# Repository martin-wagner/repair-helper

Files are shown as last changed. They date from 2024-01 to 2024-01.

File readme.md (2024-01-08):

# Reparaturhelfer

Platine mit Helferlein zur Reparatur von Röhrenradios
- Adapter für div. THT Kondensatoren auf Freiverdrahtung
- Adapter für Ladekondensator 50+50µF auf PCB mit Befestigungslöchern
- Platine "Selengleichrichter" (Bohrungen für 20mm, 27mm, 38mm und 80mm Gleichrichter, Ladekondensatoren)
- Platine "Bluetooth" (Spannungsversorgung Bluetoothmodul, Vorverstärker, Massetrennung)
- Platine "Entstörung" (Sicherheitskondensatoren, Anschluss an Chassis)

Die Platine ist < 100x100m². Somit kann diese bei den Standard Platinenherstellern bezogen werden. Der Nutzen ist im Bestückungsdruck markiert und kann leicht ausgesägt werden.

## Gleichrichter, Ladekondensatoren

Diese Platine dient als Ersatz für Selengleichrichter

- Bohrlöcher nach Standardmaßen gebräuchlicher Flachgleichrichter zur Befestigung an den vorhandenen Löchern.
- Platzierung von Entstörkondensatoren am Gleichrichter.
- Montage von verschiedneen Dropperwiderständen möglich.
- Montage der Filterkondensatoren möglich. Falls nicht benötigt kann die Platine entsprechend gekürzt werden.

## Bluetooth

Diese Platine erleichtert den Einbau eines Bluetooth Moduls ins Radio.

- Spannungsversorgung
- Vorverstärker um Ausganspegel des Bluetoothmoduls an den Line Input des Radios anzupassen
- Aufbau als Mono- oder Stereo Variante möglich
- Aufbau mit SO8 Standard OP Footprint. Möglich sind z.B. TL072 (billig) oder AD8656 (Rauscharm)
- Anschluss per Lötösen oder 3,5mm Klinke
- Montage des Bluetoothmoduls per 1mm, 1,27mm oder 2,54mm Lötleiste
- Footprint für zwei Taster, falls diese vom Bluetoothmodul benötigt werden

## Netzfilter

Diese Platine ermöglicht den Einbau eines Netzfilters mit zeitgemäßen Kondensatoren ins Gerät. Der vorgeschlagene Kondensator MUR DE1E3KX222MN ist vom Typ X1 / Y1, kann somit direkt am Netzanschluss und zwischen Netz und Chassis verwendet werden.

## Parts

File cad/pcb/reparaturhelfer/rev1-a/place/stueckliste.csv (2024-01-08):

Source: | /home/martin/elektronik/radios/reparaturhelfer/cad/pcb/reparaturhelfer/rev1-a/reparaturhelfer.kicad_sch
Date: | Mon 08 Jan 2024 13:20:33 CET
Tool: | Eeschema 7.0.10-7.0.10~ubuntu22.04.1
Generator: | /usr/share/kicad/plugins/bom_csv_grouped_by_value.py
Component Count: | 167
Collated Components:
Item | Qty | Reference(s) | Value | LibPart | Footprint | Datasheet | DNP | Bauteil | Placement | Voltage
1 | 7 | C201, C203, C207, C208, C213, C215, C216 | 100n | Device:C | Capacitor_SMD:C_0603_1608Metric | ~ |  | WE 885382206004
2 | 4 | C202, C209, C212, C214 | 1u | Device:C | Capacitor_SMD:C_0805_2012Metric | ~ |  | WE 885012207078
3 | 1 | C204 | 470u | saba-fernbedienung-rescue:CP-Device | Capacitor_THT:CP_Radial_D8.0mm_P5.00mm |  |  |  |  | 16V
4 | 3 | C205, C206, C210 | 10u | Device:C | Capacitor_SMD:C_1206_3216Metric | ~ |  | WE 885012208069
5 | 1 | C211 | ~ | saba-fernbedienung-rescue:CP-Device | Capacitor_THT:CP_Radial_D5.0mm_P2.50mm
6 | 2 | C301, C302 | 4n7 | Device:C | Capacitor_THT:C_Rect_L13.0mm_W3.0mm_P10.00mm_FKS3_FKP3_MKS4 | ~ |  | MKS4 4700/1000
7 | 4 | C303, C304, C305, C306 | 47u | saba-fernbedienung-rescue:CP-Device | Capacitor_THT:CP_Radial_D16.0mm_P7.50mm |  |  |  |  | 400V
8 | 2 | C401, C403 | C | Device:C | Capacitor_SMD:C_0805_2012Metric_Pad1.18x1.45mm_HandSolder | ~
9 | 3 | C402, C404, C406 | C | Device:C | Capacitor_THT:C_Rect_L13.0mm_W6.5mm_P7.50mm_P10.00mm | ~
10 | 1 | C405 | C | Device:C | Capacitor_SMD:C_1210_3225Metric_Pad1.33x2.70mm_HandSolder | ~
11 | 5 | C407, C409, C411, C412, C413 | C | Device:C | Capacitor_THT:C_Rect_L7.0mm_W3.5mm_P2.50mm_P5.00mm | ~
12 | 3 | C408, C410, C414 | C | Device:C | Capacitor_THT:C_Rect_L16.5mm_W7.0mm_P15.00mm_MKT | ~
13 | 3 | C415, C417, C419 | C | Device:C | Capacitor_THT:C_Rect_L10.0mm_W5.0mm_P5.00mm_P7.50mm | ~
14 | 2 | C416, C418 | C | Device:C | Capacitor_THT:C_Rect_L24.0mm_W10.1mm_P22.50mm_MKT | ~
15 | 1 | C420 | C | Device:C | Capacitor_THT:C_Rect_L29.0mm_W11.0mm_P27.50mm_MKT | ~
16 | 3 | C501, C502, C503 | 2n2 | Device:C | Capacitor_THT:C_Disc_D11.0mm_W5.0mm_P10.00mm | ~ |  | MUR DE1E3KX222MN
17 | 4 | D201, D202, D203, D204 | B140-E3 | Diode:B140-E3 | Diode_SMD:D_SMA | http://www.vishay.com/docs/88946/b120.pdf |  | Vishay B140-E3/61T
18 | 4 | D301, D302, D303, D304 | 1N4007 | Device:D | Diode_THT:D_A-405_P10.16mm_Horizontal | ~
19 | 3 | FID201, FID202, FID203 | Fiducial | Mechanical:Fiducial | Fiducial:Fiducial_1mm_Mask2mm | ~
20 | 5 | H201, H202, H203, H204, H502 | MountingHole | Mechanical:MountingHole | MountingHole:MountingHole_3.2mm_M3 | ~
21 | 8 | H301, H302, H303, H304, H305, H306, H307, H501 | MountingHole_Pad | Mechanical:MountingHole_Pad | MountingHole:MountingHole_3.2mm_M3_Pad | ~
22 | 1 | J201 | Conn_01x02 | Connector_Generic:Conn_01x02 | Connector_PinHeader_2.54mm:PinHeader_1x02_P2.54mm_Vertical | ~
23 | 1 | J202 | Conn_01x12 | Connector_Generic:Conn_01x12 | Connector_PinHeader_1.27mm:PinHeader_1x12_P1.27mm_Vertical | ~
24 | 1 | J203 | Conn_01x15 | Connector_Generic:Conn_01x15 | Connector_PinHeader_1.00mm:PinHeader_1x15_P1.00mm_Vertical | ~
25 | 1 | J204 | Conn_01x07 | Connector_Generic:Conn_01x07 | Connector_PinHeader_2.54mm:PinHeader_1x07_P2.54mm_Vertical | ~
26 | 1 | J205 | Conn_01x05 | Connector_Generic:Conn_01x05 | Connector_PinHeader_2.54mm:PinHeader_1x05_P2.54mm_Vertical | ~
27 | 1 | J206 | AudioJack3 | Connector:AudioJack3 | Connector_Audio:Jack_3.5mm_CUI_SJ1-3523N_Horizontal | https://www.farnell.com/datasheets/2028381.pdf |  | CLIFF FC68131
28 | 65 | J207, J208, J209, J301, J302, J303, J304, J305, J306, J307, J308, J309, J310, J311, J312, J313, J314, J315, J316, J317, J318, J319, J320, J321, J322, J323, J324, J325, J326, J401, J402, J403, J404, J405, J406, J407, J408, J409, J410, J411, J412, J413, J414, J415, J416, J417, J418, J419, J420, J421, J422, J423, J424, J425, J426, J427, J428, J429, J430, J431, J432, J433, J434, J435, J436 | Conn_01x01 | Connector_Generic:Conn_01x01 | Connector_PinHeader_2.54mm:PinHeader_1x01_P2.54mm_Vertical | ~
29 | 1 | J501 | Conn_01x03 | Connector_Generic:Conn_01x03 | Connector_PinHeader_2.54mm:PinHeader_1x03_P2.54mm_Vertical | ~
30 | 2 | R201, R211 | 1k | Device:R | Resistor_SMD:R_0603_1608Metric | ~
31 | 6 | R202, R205, R206, R212, R213, R214 | 100k | Device:R | Resistor_SMD:R_0603_1608Metric | ~
32 | 2 | R203, R204 | 0 | Device:R | Resistor_SMD:R_0603_1608Metric | ~ |  |  | NP
33 | 2 | R207, R215 | 10k | Device:R | Resistor_SMD:R_0603_1608Metric | ~
34 | 4 | R208, R216, R217, R218 | 1M | Device:R | Resistor_SMD:R_0603_1608Metric | ~ |  |  | NP
35 | 2 | R209, R210 | 220 | Device:R | Resistor_SMD:R_0603_1608Metric | ~
36 | 2 | RV201, RV202 | 20k lin | saba-fernbedienung-rescue:R_POT-Device | Potentiometer_SMD:Potentiometer_Vishay_TS53YJ_Vertical |  |  | 23A-20K
37 | 2 | SW201, SW202 | SW_Push | Switch:SW_Push | Button_Switch_THT:SW_PUSH_6mm | ~
38 | 2 | T201, T202 | 1:1 | Device:Transformer_1P_1S | local:Transformer_NF_EI14 | ~ |  |  | NP
39 | 1 | U201 | 1117 5.0V | Regulator_Linear:AP1117-50 | Package_TO_SOT_SMD:TO-252-3_TabPin2 | http://www.diodes.com/datasheets/AP1117.pdf |  | LD1117DT50CTR
40 | 1 | U202 | AD8656 | saba-fernbedienung-rescue:Opamp_Dual_Generic-Device | Package_SO:SOIC-8_3.9x4.9mm_P1.27mm | https://www.analog.com/media/en/technical-documentation/data-sheets/AD8655_8656.pdf |  | AD8656ARZ

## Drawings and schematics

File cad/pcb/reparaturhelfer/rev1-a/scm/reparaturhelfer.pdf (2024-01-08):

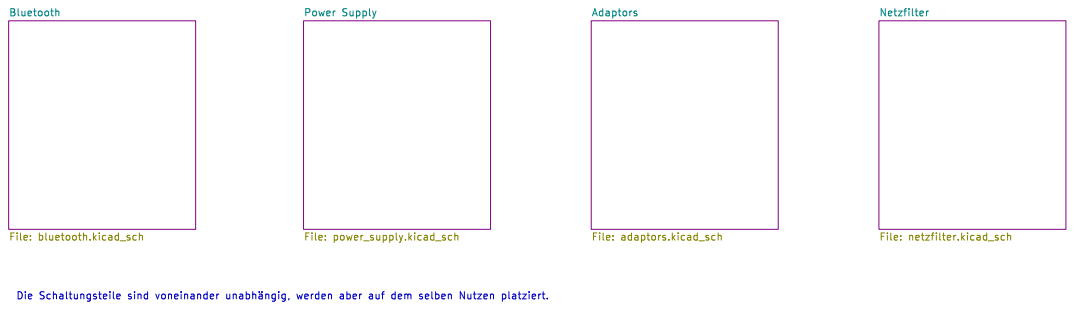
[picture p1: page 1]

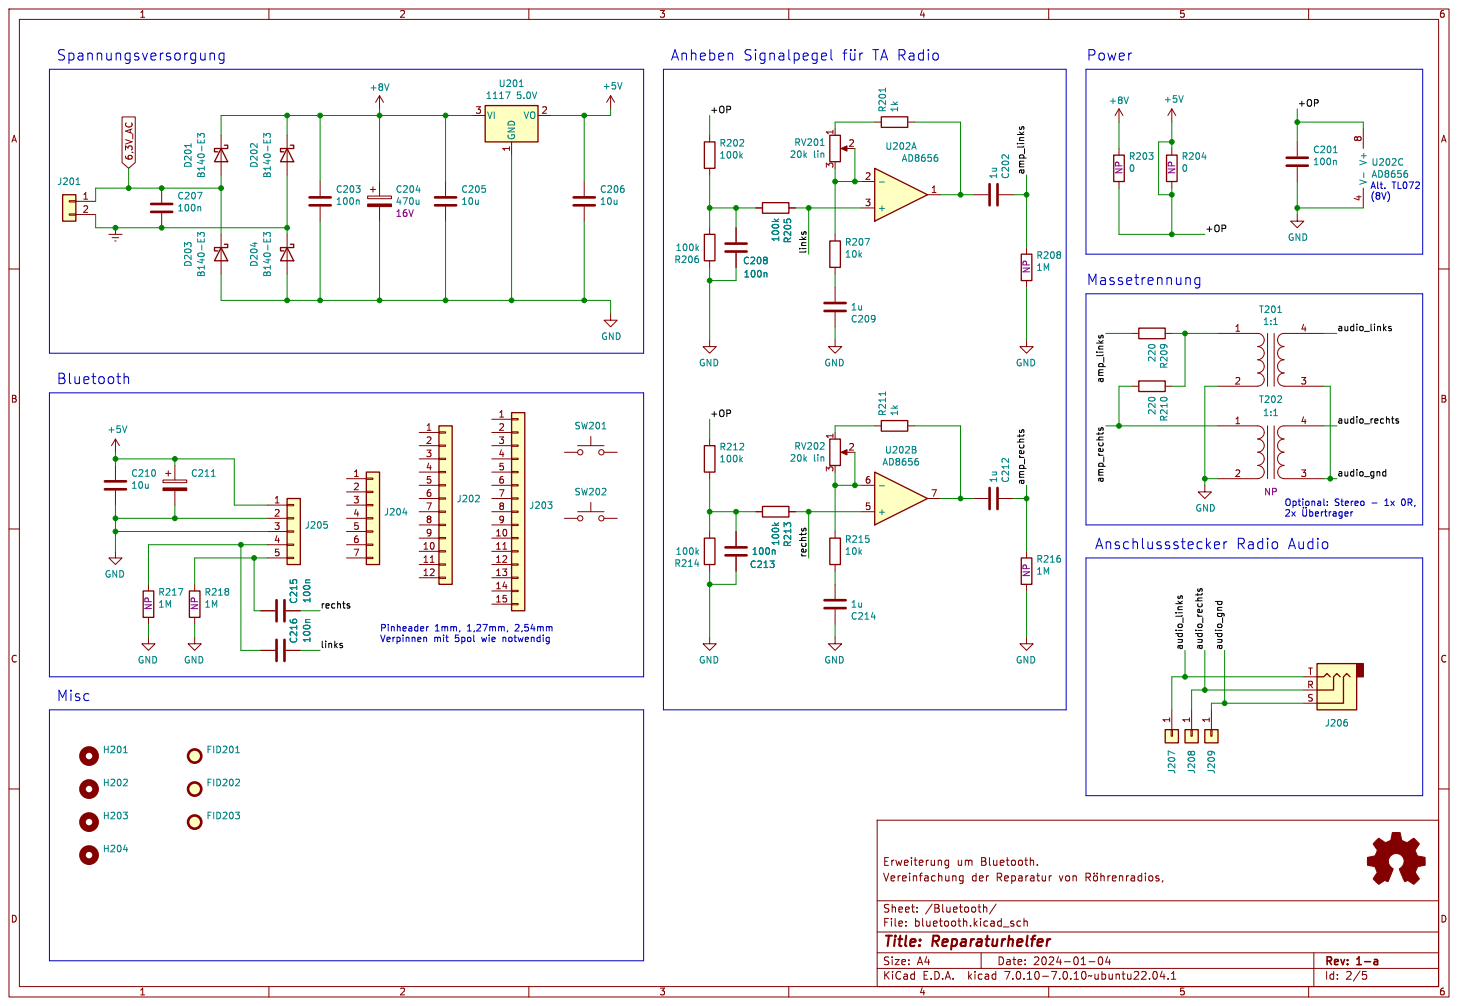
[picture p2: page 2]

Verpinnen mit 5pol wie notwendig

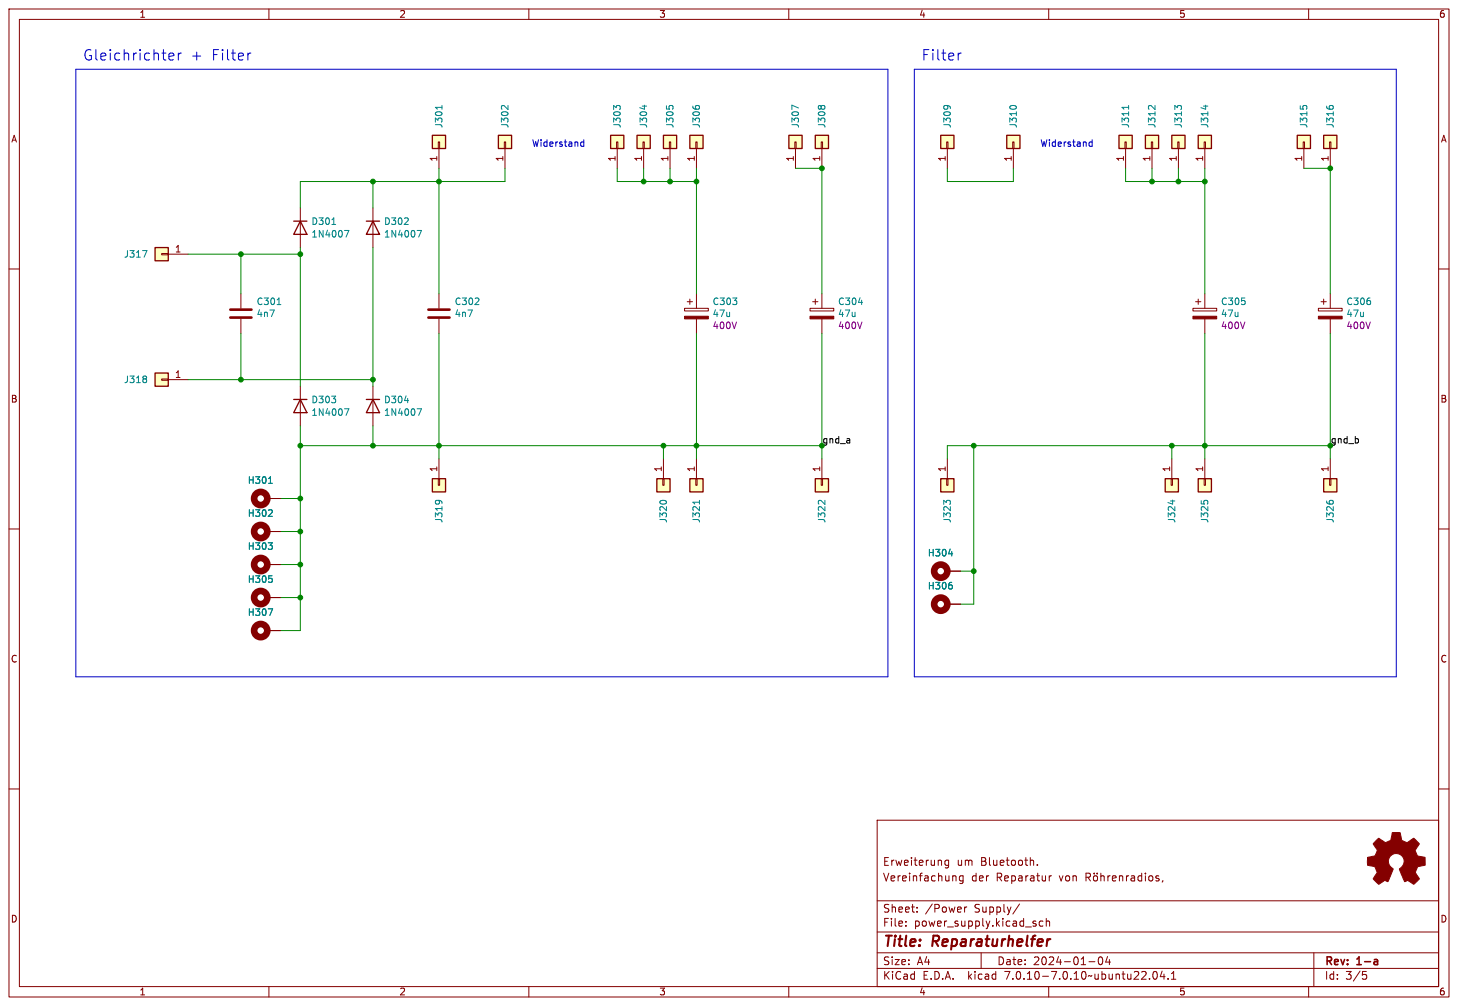
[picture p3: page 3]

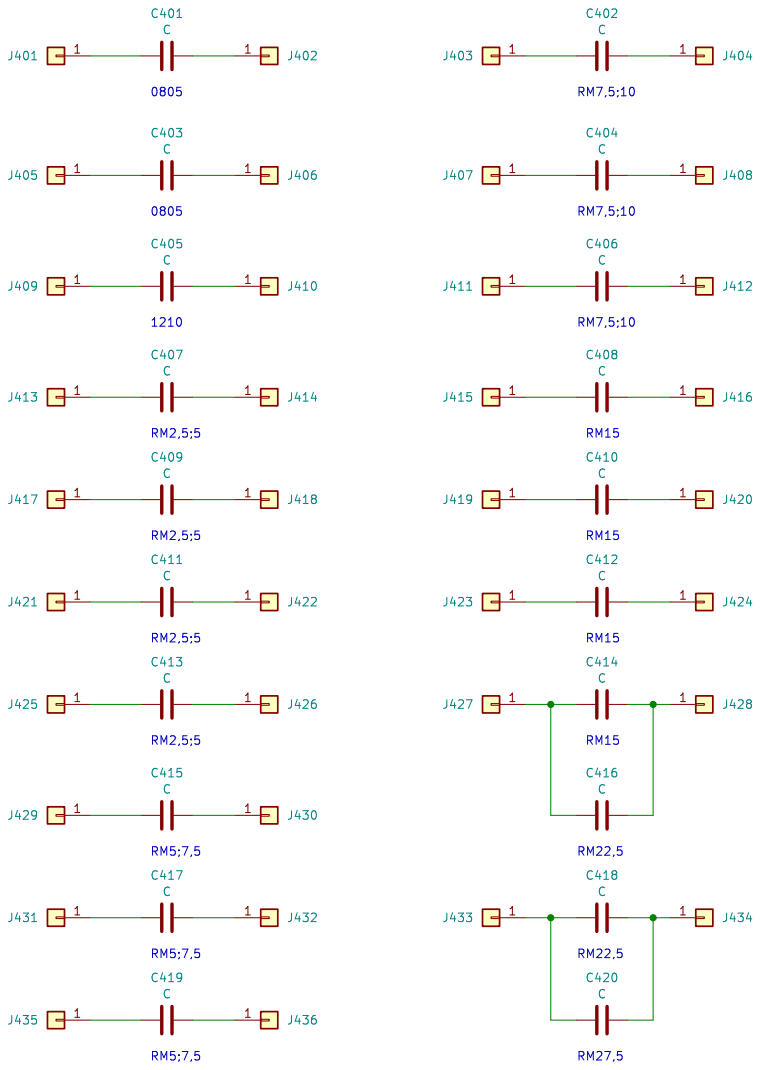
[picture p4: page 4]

Id: 4/5 Title: Reparaturhelfer File: adaptors.kicad_sch Sheet: /Adaptors/

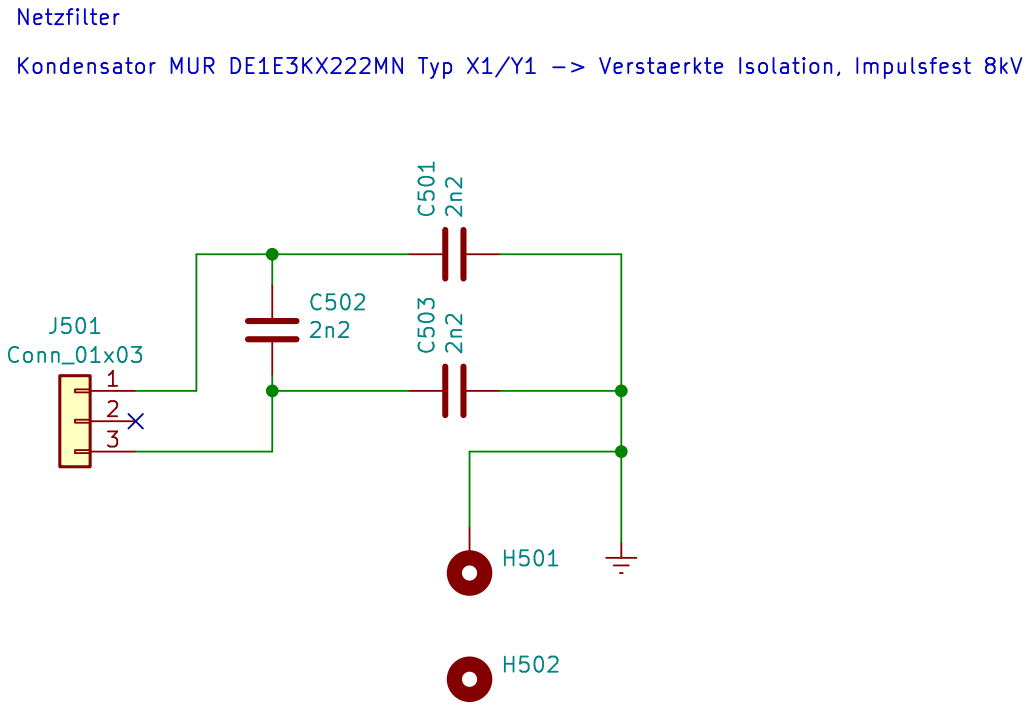
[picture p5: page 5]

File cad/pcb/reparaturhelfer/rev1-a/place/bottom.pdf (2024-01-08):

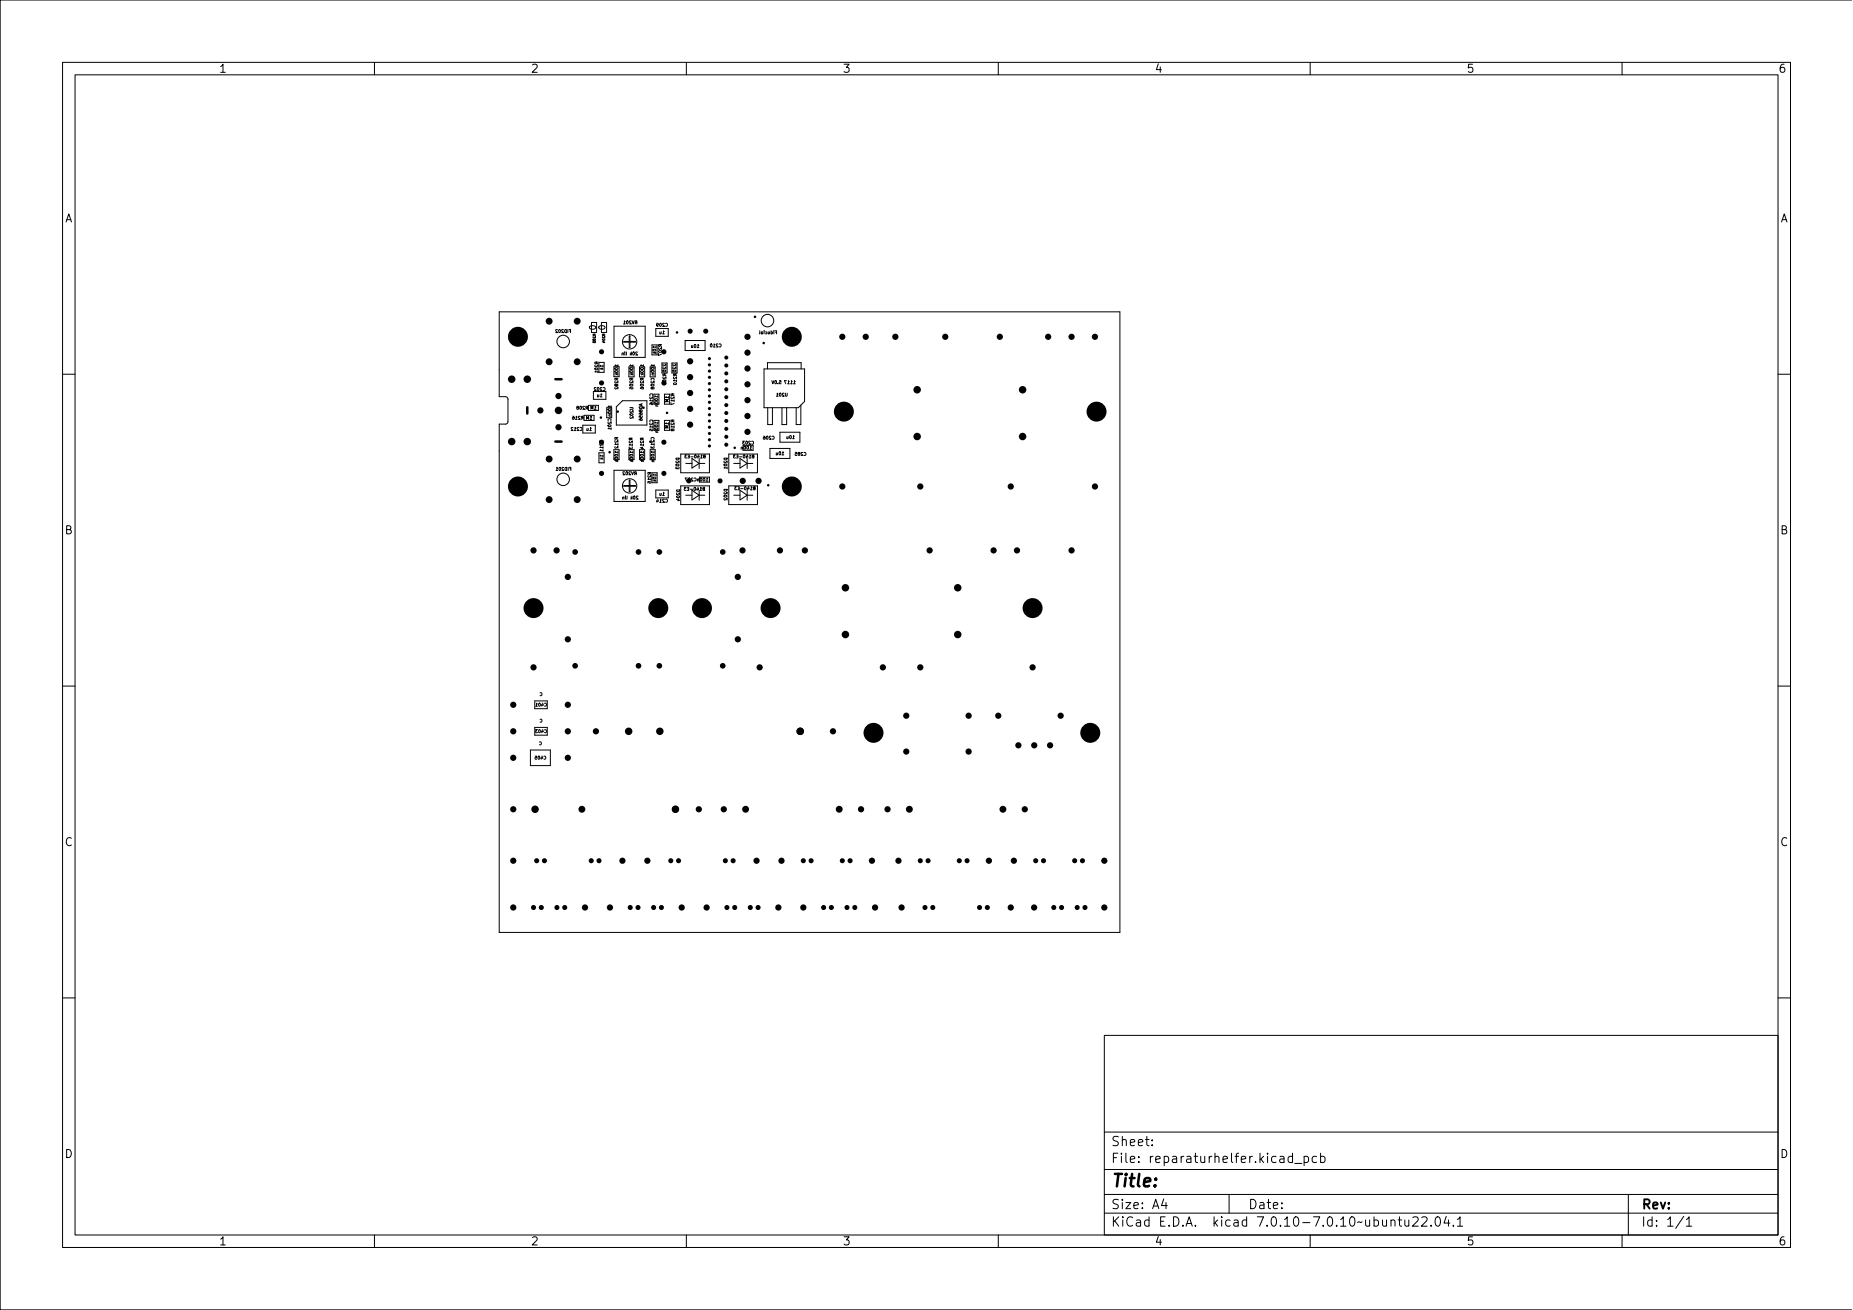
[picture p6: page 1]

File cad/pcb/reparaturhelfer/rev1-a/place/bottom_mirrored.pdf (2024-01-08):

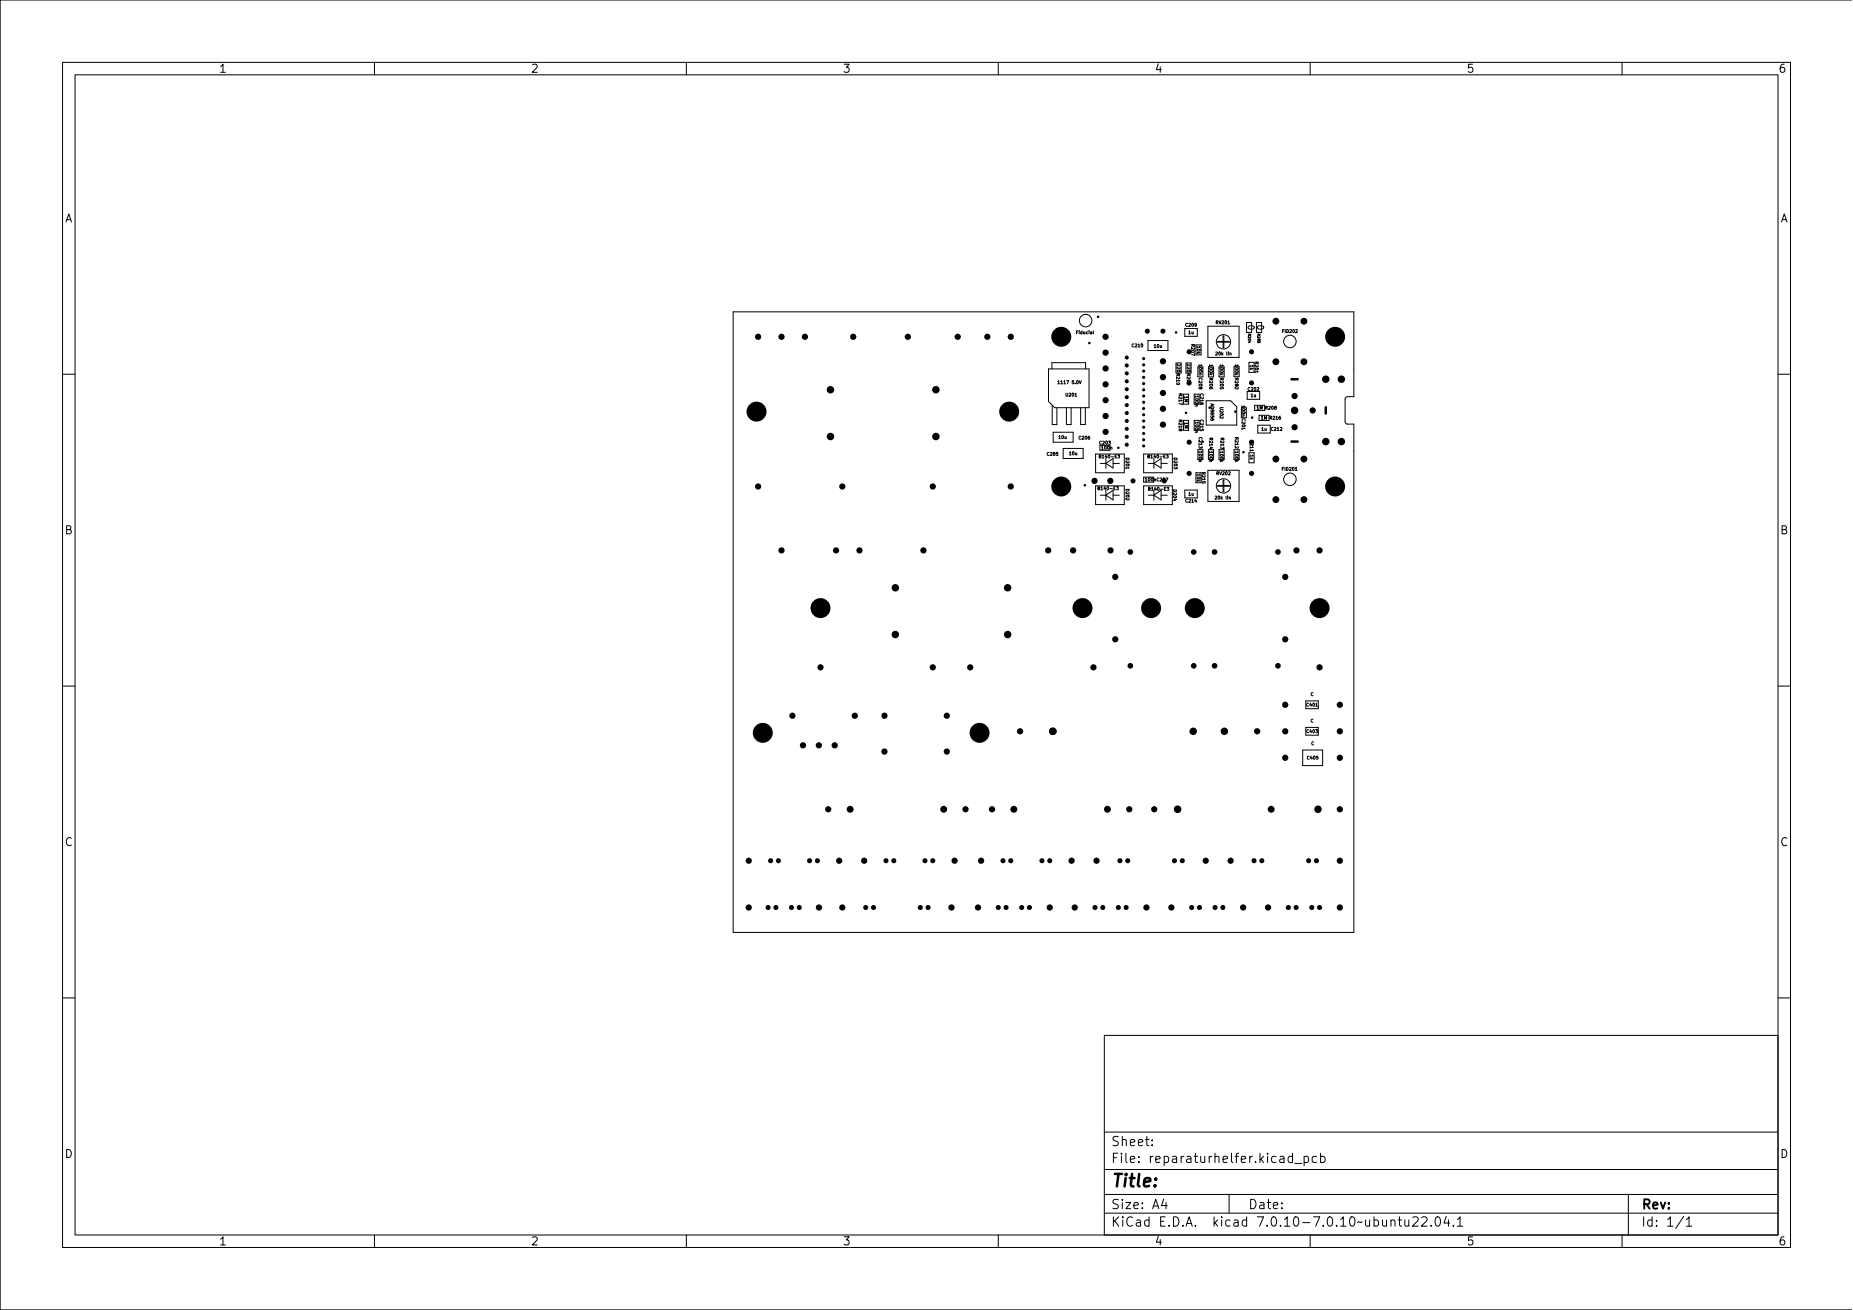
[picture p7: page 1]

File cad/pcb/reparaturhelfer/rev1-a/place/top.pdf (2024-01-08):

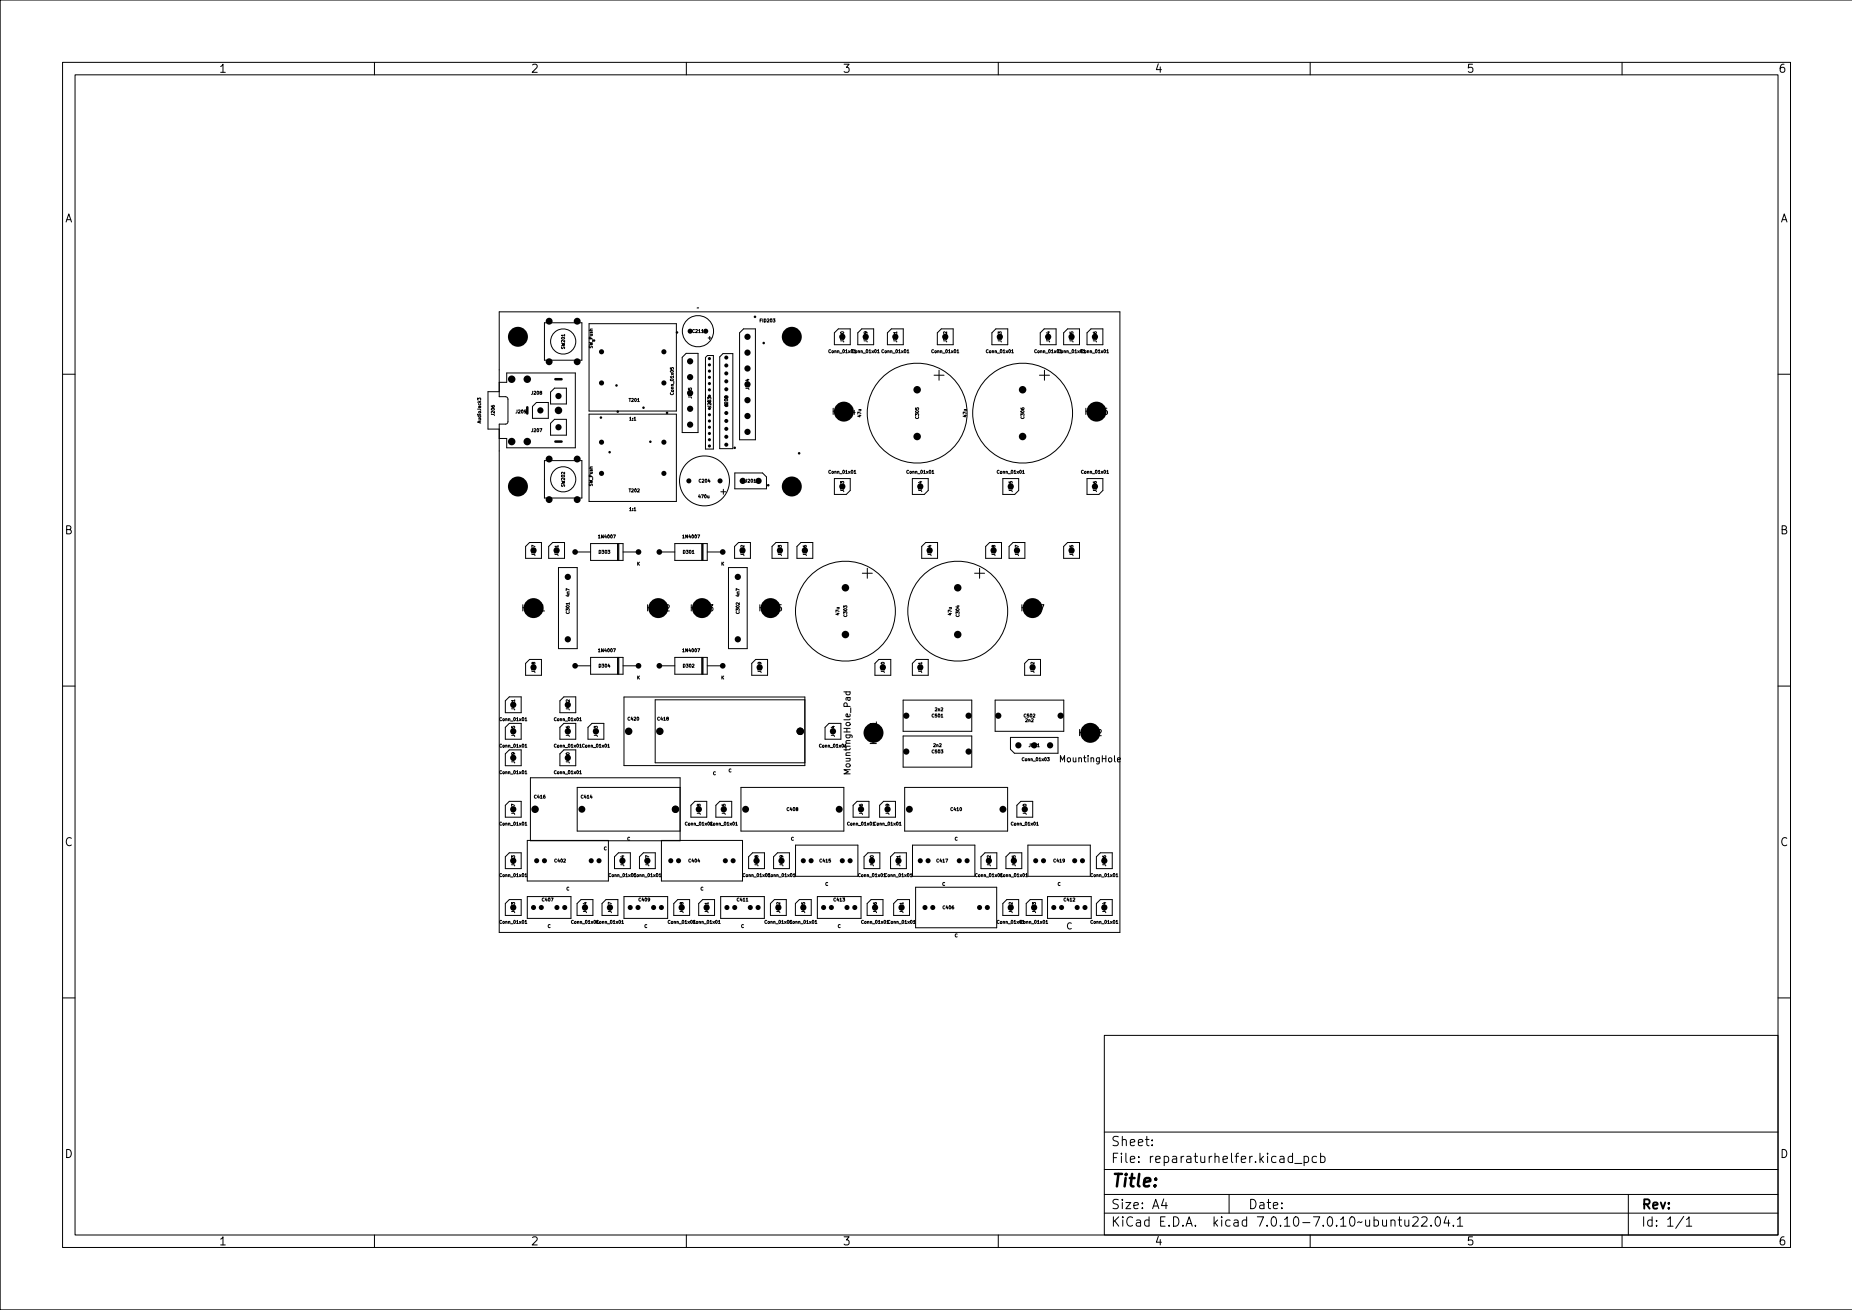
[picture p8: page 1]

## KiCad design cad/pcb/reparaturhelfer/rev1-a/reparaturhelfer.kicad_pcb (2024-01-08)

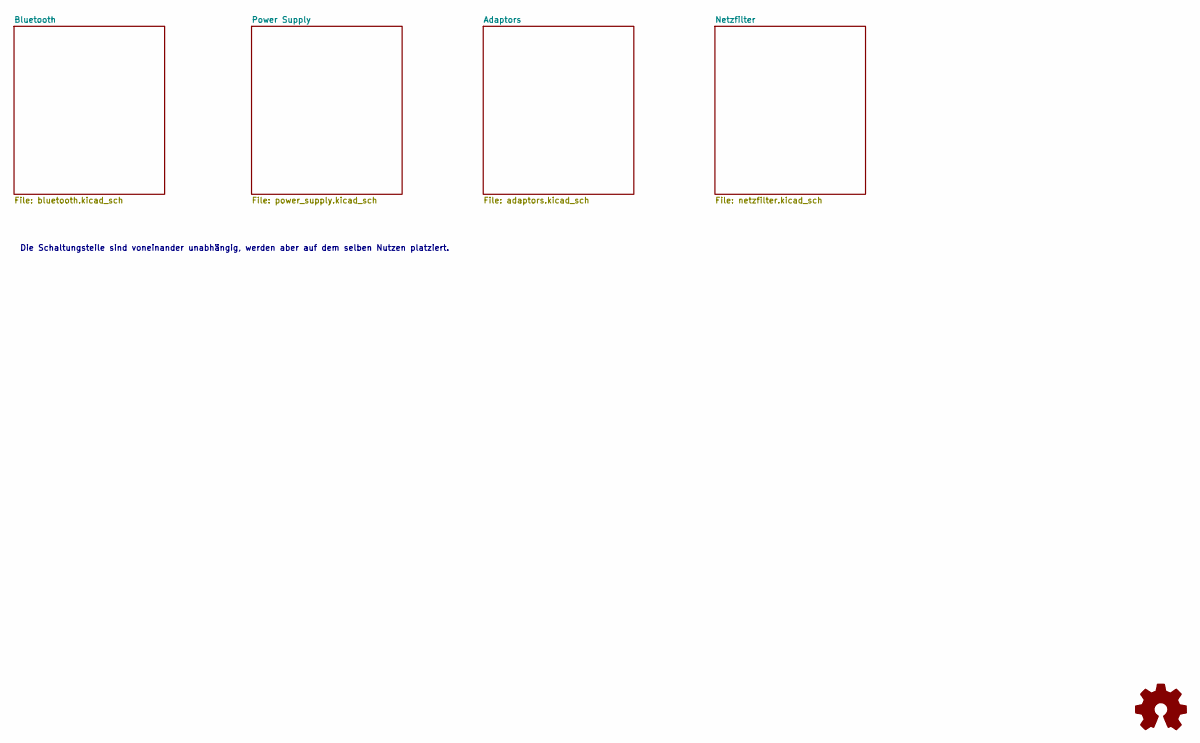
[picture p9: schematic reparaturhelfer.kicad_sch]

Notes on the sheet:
Die Schaltungsteile sind voneinander unabhängig, werden aber auf dem selben Nutzen platziert.

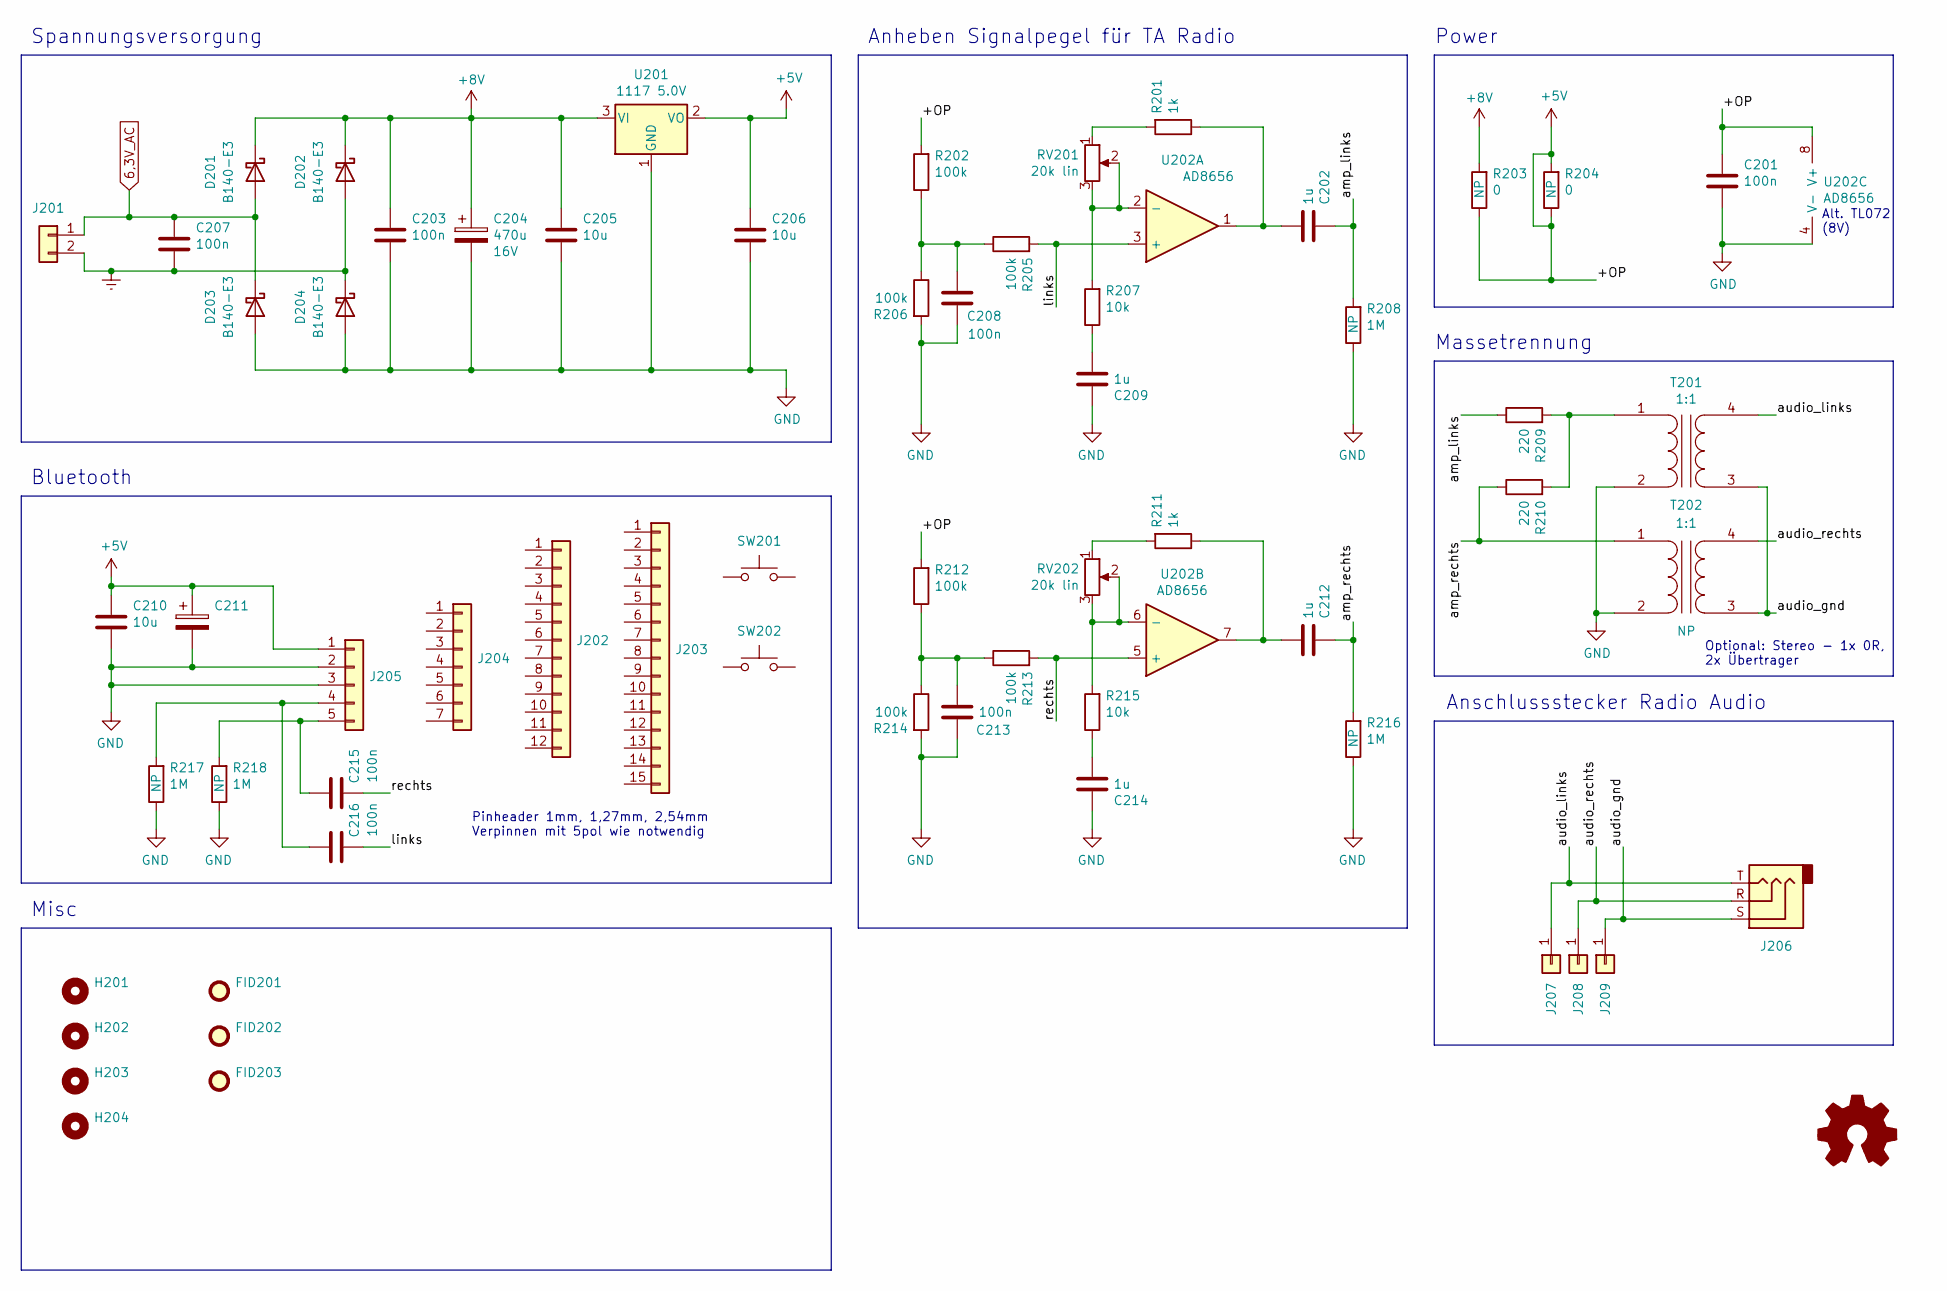
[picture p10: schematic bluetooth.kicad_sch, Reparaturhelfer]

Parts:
C201, C203, C207, C208, C213, C215, C216: 100n; C_0603_1608Metric
C202, C209, C212, C214: 1u; C_0805_2012Metric
C204: 470u; CP_Radial_D8.0mm_P5.00mm; Voltage 16V
C205, C206, C210: 10u; C_1206_3216Metric
C211: CP_Radial_D5.0mm_P2.50mm
D201, D202, D203, D204: B140-E3; D_SMA
FID201, FID202, FID203: Fiducial; Fiducial_1mm_Mask2mm
H201, H202, H203, H204: MountingHole; MountingHole_3.2mm_M3
J201: Conn_01x02; PinHeader_1x02_P2.54mm_Vertical
J202: Conn_01x12; PinHeader_1x12_P1.27mm_Vertical
J203: Conn_01x15; PinHeader_1x15_P1.00mm_Vertical
J204: Conn_01x07; PinHeader_1x07_P2.54mm_Vertical
J205: Conn_01x05; PinHeader_1x05_P2.54mm_Vertical
J206: AudioJack3; Jack_3.5mm_CUI_SJ1-3523N_Horizontal
J207, J208, J209: Conn_01x01; PinHeader_1x01_P2.54mm_Vertical
R201, R211: 1k; R_0603_1608Metric
R202, R205, R206, R212, R213, R214: 100k; R_0603_1608Metric
R203, R204: 0; R_0603_1608Metric
R207, R215: 10k; R_0603_1608Metric
R208, R216, R217, R218: 1M; R_0603_1608Metric
R209, R210: 220; R_0603_1608Metric
RV201, RV202: 20k lin; Potentiometer_Vishay_TS53YJ_Vertical
SW201, SW202: SW_Push; SW_PUSH_6mm
T201, T202: 1:1; Transformer_NF_EI14
U201: 1117 5.0V; TO-252-3_TabPin2
U202: AD8656; SOIC-8_3.9x4.9mm_P1.27mm

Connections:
6,3V_AC: C207.1, D201.2 (A), D203.1 (K), J201.1
+5V: C201.1, C206.1, C210.1, C211.1, J205.1, R202.2, R203.1, R204.1, R204.2, R212.2, U201.2 (VO), U202.8 (V+)
+8V: C203.1, C204.1, C205.1, D201.1 (K), D202.1 (K), R203.2, U201.3 (VI)
/Bluetooth/amp_links: C202.1, R208.2, R209.1
/Bluetooth/amp_rechts: C212.1, R210.1, R216.2, T202.1 (AA)
/Bluetooth/audio_gnd: J206.S, J209.1, T201.3 (SA), T202.3 (SA)
/Bluetooth/audio_links: J206.T, J207.1, T201.4 (SB)
/Bluetooth/audio_rechts: J206.R, J208.1, T202.4 (SB)
/Bluetooth/links: C216.1, R205.2, U202.3 (+)
/Bluetooth/rechts: C215.1, R213.2, U202.5 (+)
Earth: C207.2, D202.2 (A), D204.1 (K), J201.2; also elsewhere on the board
GND: C201.2, C203.2, C204.2, C205.2, C206.2, C208.1, C209.1, C210.2, C211.2, C213.2, C214.1, D203.2 (A), D204.2 (A), J205.2, J205.3, R206.2, R208.1, R214.2, R216.1, R217.1, R218.1, T201.2 (AB), T202.2 (AB), U201.1 (GND), U202.4 (V-)
unnamed: C202.2, R201.1, U202.1
unnamed: C208.2, R202.1, R205.1, R206.1
unnamed: C209.2, R207.1
unnamed: C212.2, R211.1, U202.7
unnamed: C213.1, R212.1, R213.1, R214.1
unnamed: C214.2, R215.1
unnamed: C216.2, J205.4, R217.2
unnamed: C215.2, J205.5, R218.2
unnamed: R201.2, RV201.1
unnamed: R211.2, RV202.1
unnamed: R209.2, R210.2, T201.1 (AA)
unnamed: R207.2, RV201.2, RV201.3, U202.2 (-)
unnamed: R215.2, RV202.2, RV202.3, U202.6 (-)

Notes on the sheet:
Anheben Signalpegel für TA Radio
Anschlussstecker Radio Audio
Power
Optional: Stereo - 1x 0R, 2x Übertrager
Massetrennung
Alt. TL072 (8V)
Pinheader 1mm, 1,27mm, 2,54mm Verpinnen mit 5pol wie notwendig
Misc
Spannungsversorgung
Bluetooth

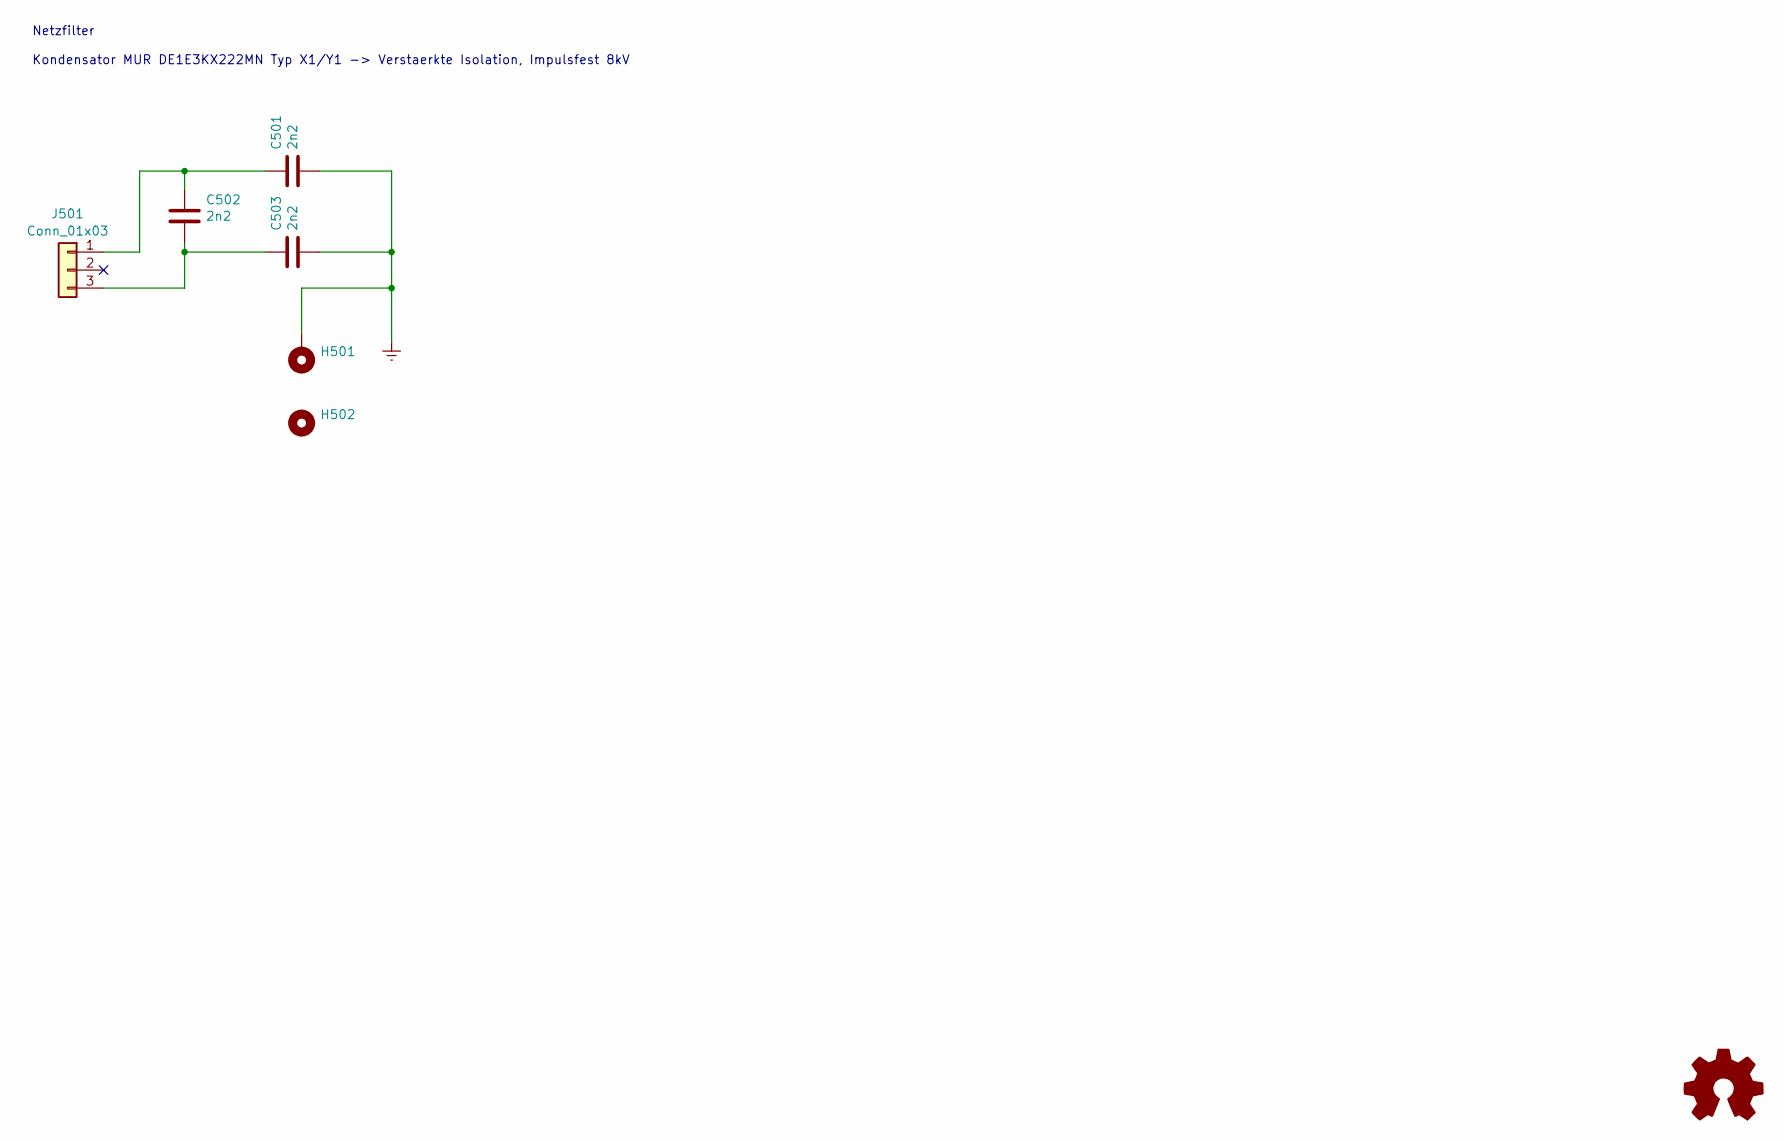
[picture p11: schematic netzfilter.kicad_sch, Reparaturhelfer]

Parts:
C501, C502, C503: 2n2; C_Disc_D11.0mm_W5.0mm_P10.00mm
H501: MountingHole_Pad; MountingHole_3.2mm_M3_Pad
H502: MountingHole; MountingHole_3.2mm_M3
J501: Conn_01x03; PinHeader_1x03_P2.54mm_Vertical

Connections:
Earth: C501.2, C503.2, H501.1; also elsewhere on the board
unnamed: C501.1, C502.1, J501.1
unnamed: C502.2, C503.1, J501.3

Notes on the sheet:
Netzfilter Kondensator MUR DE1E3KX222MN Typ X1/Y1 -> Verstaerkte Isolation, Impulsfest 8kV

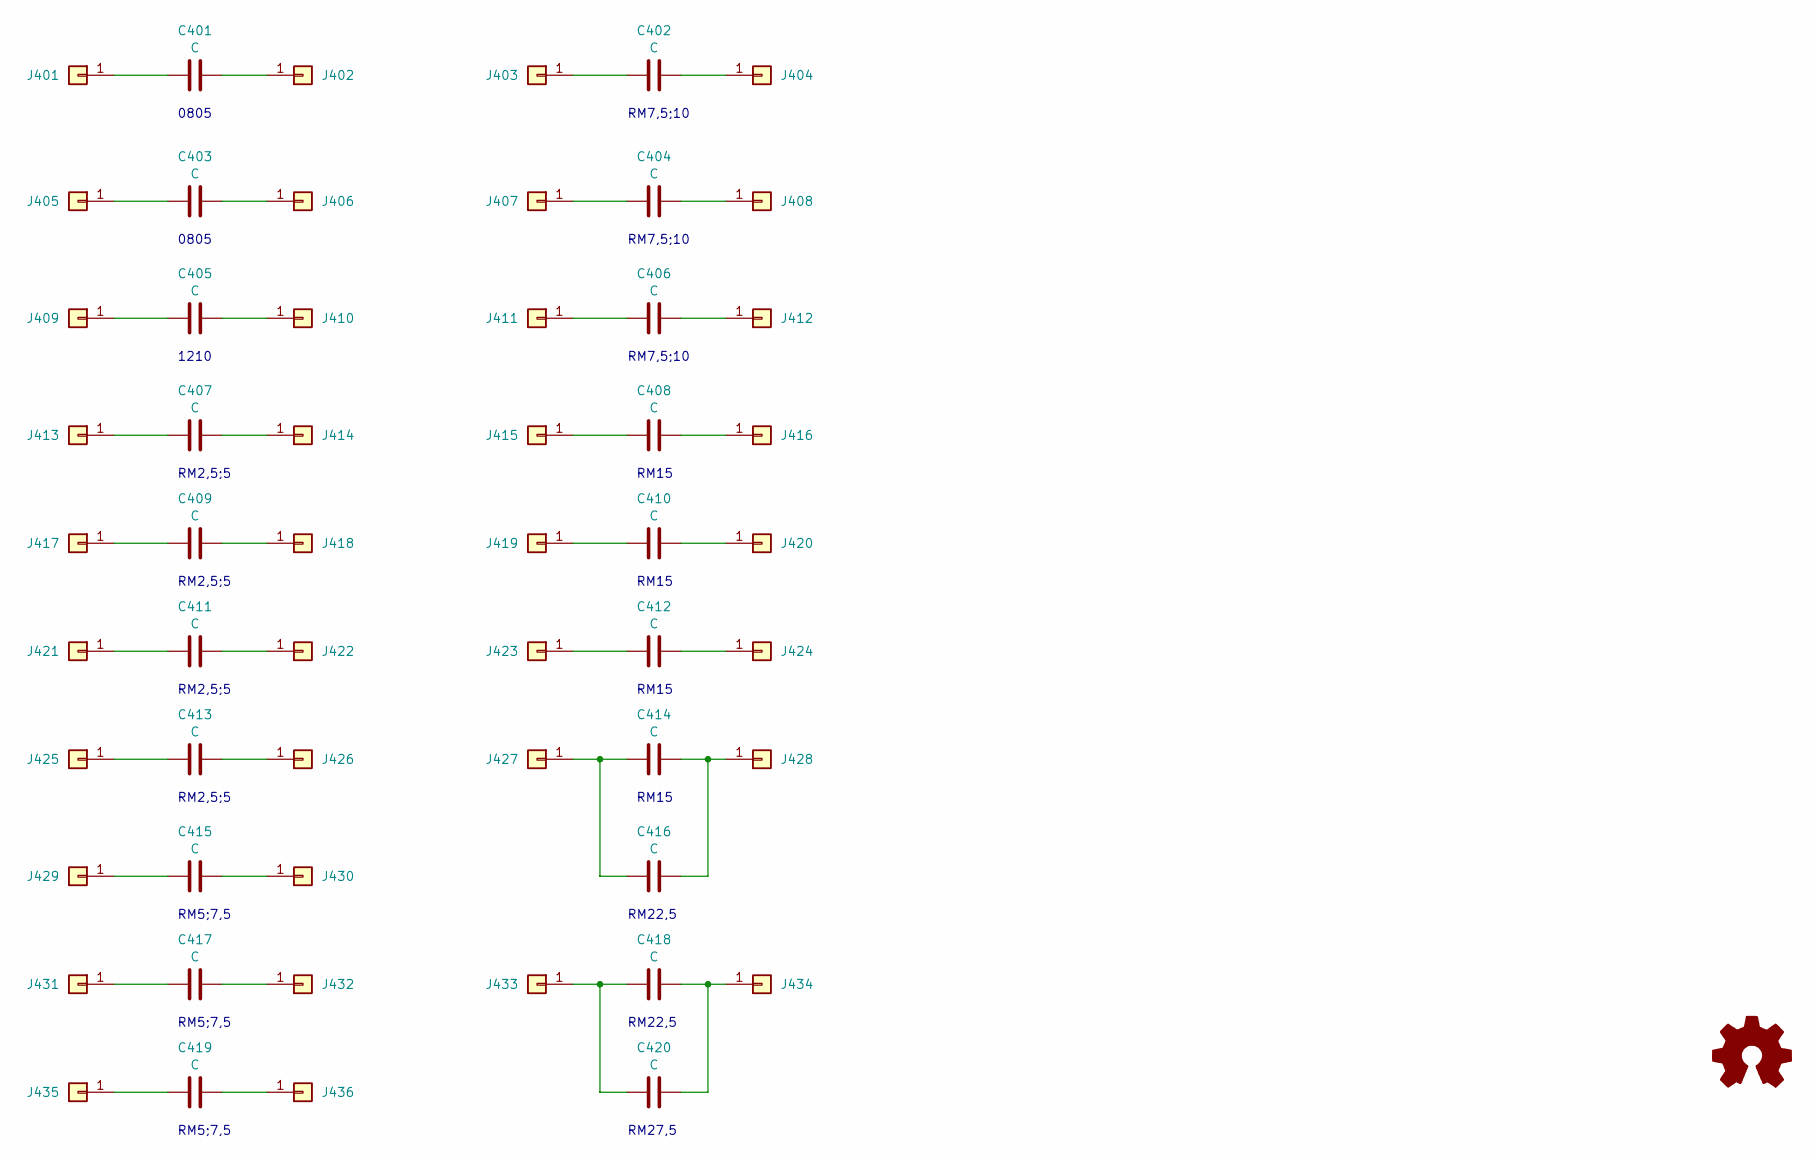
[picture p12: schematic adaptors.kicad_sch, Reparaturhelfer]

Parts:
C401, C403: C; C_0805_2012Metric_Pad1.18x1.45mm_HandSolder
C402, C404, C406: C; C_Rect_L13.0mm_W6.5mm_P7.50mm_P10.00mm
C405: C; C_1210_3225Metric_Pad1.33x2.70mm_HandSolder
C407, C409, C411, C412, C413: C; C_Rect_L7.0mm_W3.5mm_P2.50mm_P5.00mm
C408, C410, C414: C; C_Rect_L16.5mm_W7.0mm_P15.00mm_MKT
C415, C417, C419: C; C_Rect_L10.0mm_W5.0mm_P5.00mm_P7.50mm
C416, C418: C; C_Rect_L24.0mm_W10.1mm_P22.50mm_MKT
C420: C; C_Rect_L29.0mm_W11.0mm_P27.50mm_MKT
J401, J402, J403, J404, J405, J406, J407, J408, J409, J410, J411, J412, J413, J414, J415, J416, J417, J418, J419, J420, J421, J422, J423, J424, J425, J426, J427, J428, J429, J430, J431, J432, J433, J434, J435, J436: Conn_01x01; PinHeader_1x01_P2.54mm_Vertical

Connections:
unnamed: C401.1, J401.1
unnamed: C401.2, J402.1
unnamed: C402.1, J403.1
unnamed: C402.2, J404.1
unnamed: C403.1, J405.1
unnamed: C403.2, J406.1
unnamed: C404.1, J407.1
unnamed: C404.2, J408.1
unnamed: C405.1, J409.1
unnamed: C405.2, J410.1
unnamed: C406.1, J411.1
unnamed: C406.2, J412.1
unnamed: C407.1, J413.1
unnamed: C407.2, J414.1
unnamed: C408.1, J415.1
unnamed: C408.2, J416.1
unnamed: C409.1, J417.1
unnamed: C409.2, J418.1
unnamed: C410.1, J419.1
unnamed: C410.2, J420.1
unnamed: C411.1, J421.1
unnamed: C411.2, J422.1
unnamed: C412.1, J423.1
unnamed: C412.2, J424.1
unnamed: C413.1, J425.1
unnamed: C413.2, J426.1
unnamed: C414.1, C416.1, J427.1
unnamed: C414.2, C416.2, J428.1
unnamed: C415.1, J429.1
unnamed: C415.2, J430.1
unnamed: C417.1, J431.1
unnamed: C417.2, J432.1
unnamed: C418.1, C420.1, J433.1
unnamed: C418.2, C420.2, J434.1
unnamed: C419.1, J435.1
unnamed: C419.2, J436.1

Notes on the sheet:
RM7,5;10
0805
RM5;7,5
RM15
RM2,5;5
RM22,5
1210
RM27,5

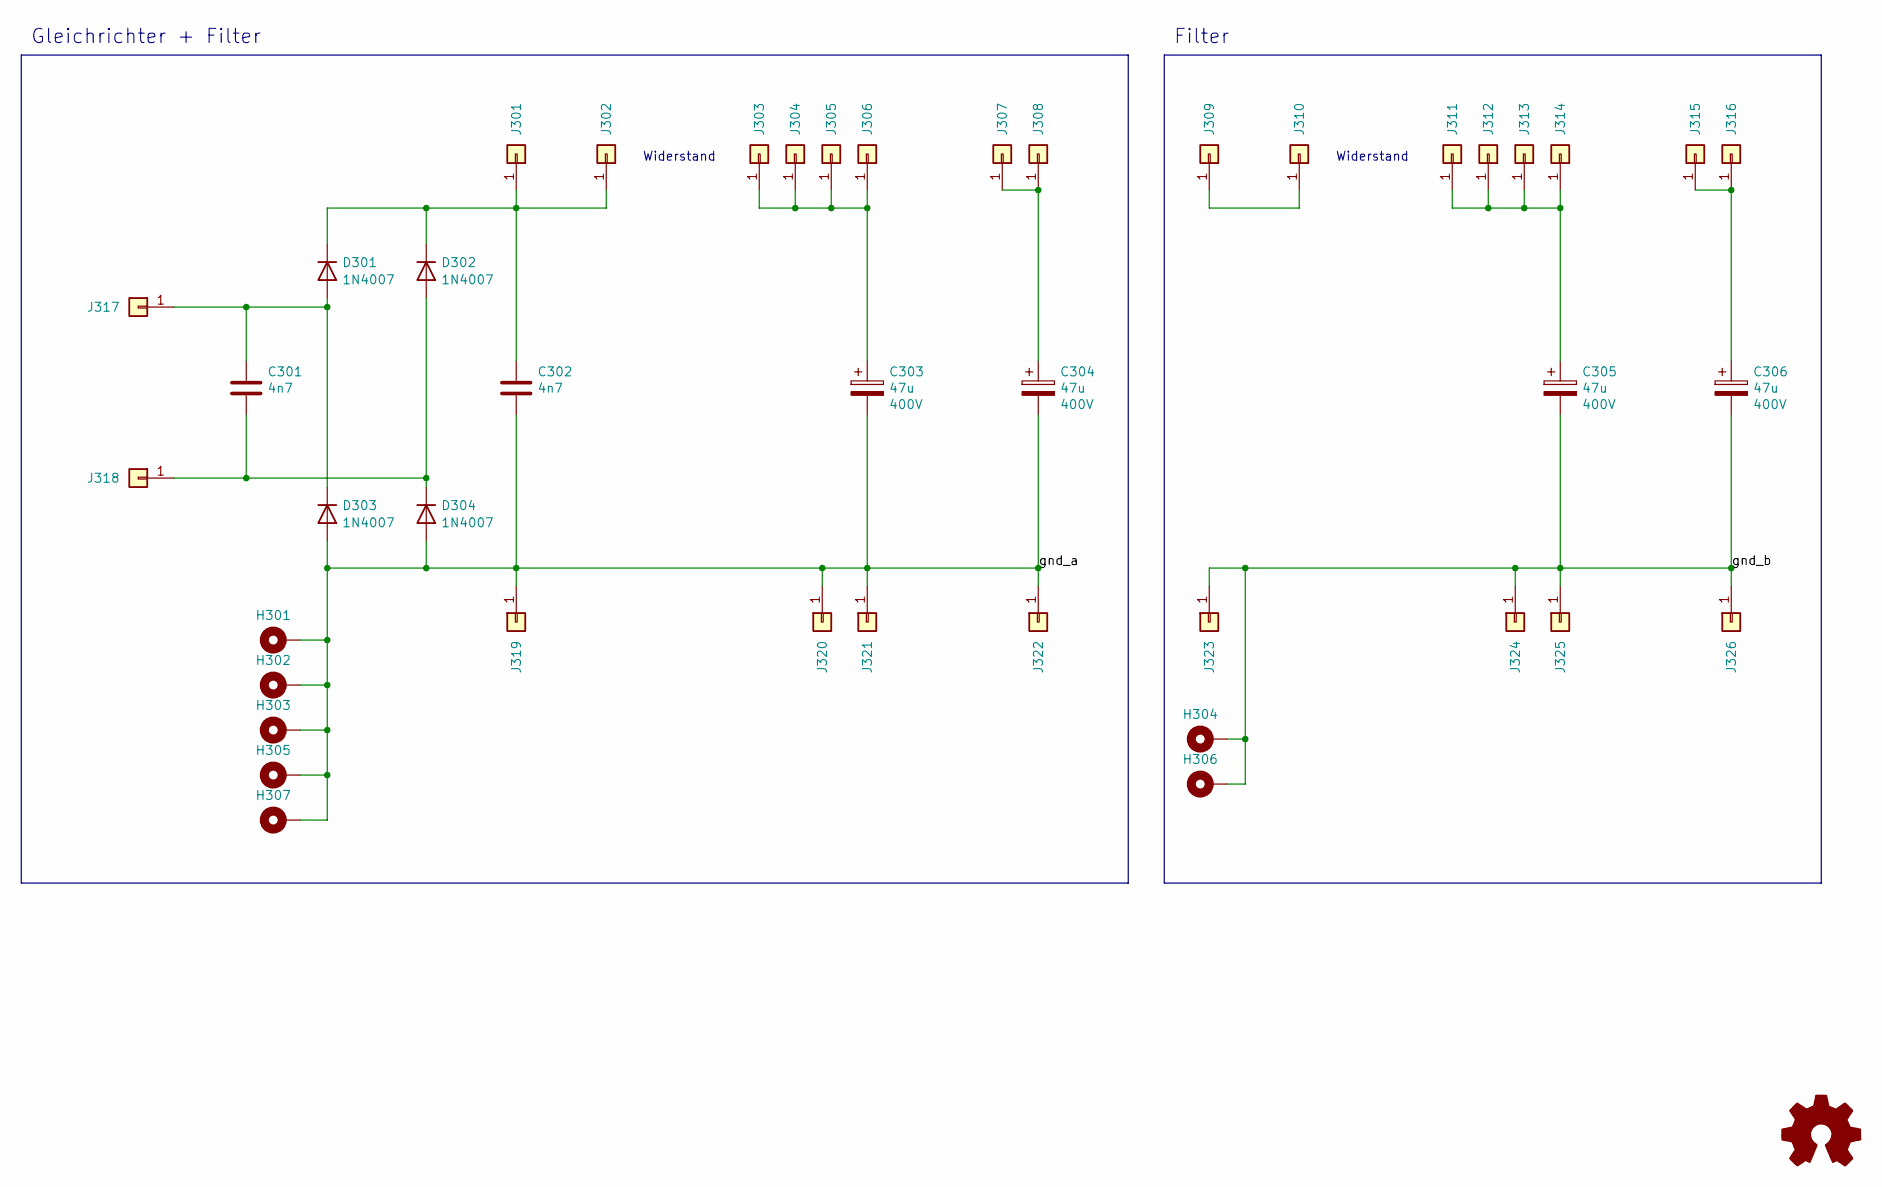
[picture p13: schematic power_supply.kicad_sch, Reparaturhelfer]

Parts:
C301, C302: 4n7; C_Rect_L13.0mm_W3.0mm_P10.00mm_FKS3_FKP3_MKS4
C303, C304, C305, C306: 47u; CP_Radial_D16.0mm_P7.50mm; Voltage 400V
D301, D302, D303, D304: 1N4007; D_A-405_P10.16mm_Horizontal
H301, H302, H303, H304, H305, H306, H307: MountingHole_Pad; MountingHole_3.2mm_M3_Pad
J301, J302, J303, J304, J305, J306, J307, J308, J309, J310, J311, J312, J313, J314, J315, J316, J317, J318, J319, J320, J321, J322, J323, J324, J325, J326: Conn_01x01; PinHeader_1x01_P2.54mm_Vertical

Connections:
/Power Supply/gnd_a: C302.2, C303.2, C304.2, D303.2 (A), D304.2 (A), H301.1, H302.1, H303.1, H305.1, H307.1, J319.1, J320.1, J321.1, J322.1
/Power Supply/gnd_b: C305.2, C306.2, H304.1, H306.1, J323.1, J324.1, J325.1, J326.1
unnamed: C301.1, D301.2 (A), D303.1 (K), J317.1
unnamed: C302.1, D301.1 (K), D302.1 (K), J301.1, J302.1
unnamed: C301.2, D302.2 (A), D304.1 (K), J318.1
unnamed: C303.1, J303.1, J304.1, J305.1, J306.1
unnamed: C304.1, J307.1, J308.1
unnamed: J309.1, J310.1
unnamed: C305.1, J311.1, J312.1, J313.1, J314.1
unnamed: C306.1, J315.1, J316.1

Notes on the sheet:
Widerstand
Gleichrichter + Filter
Filter

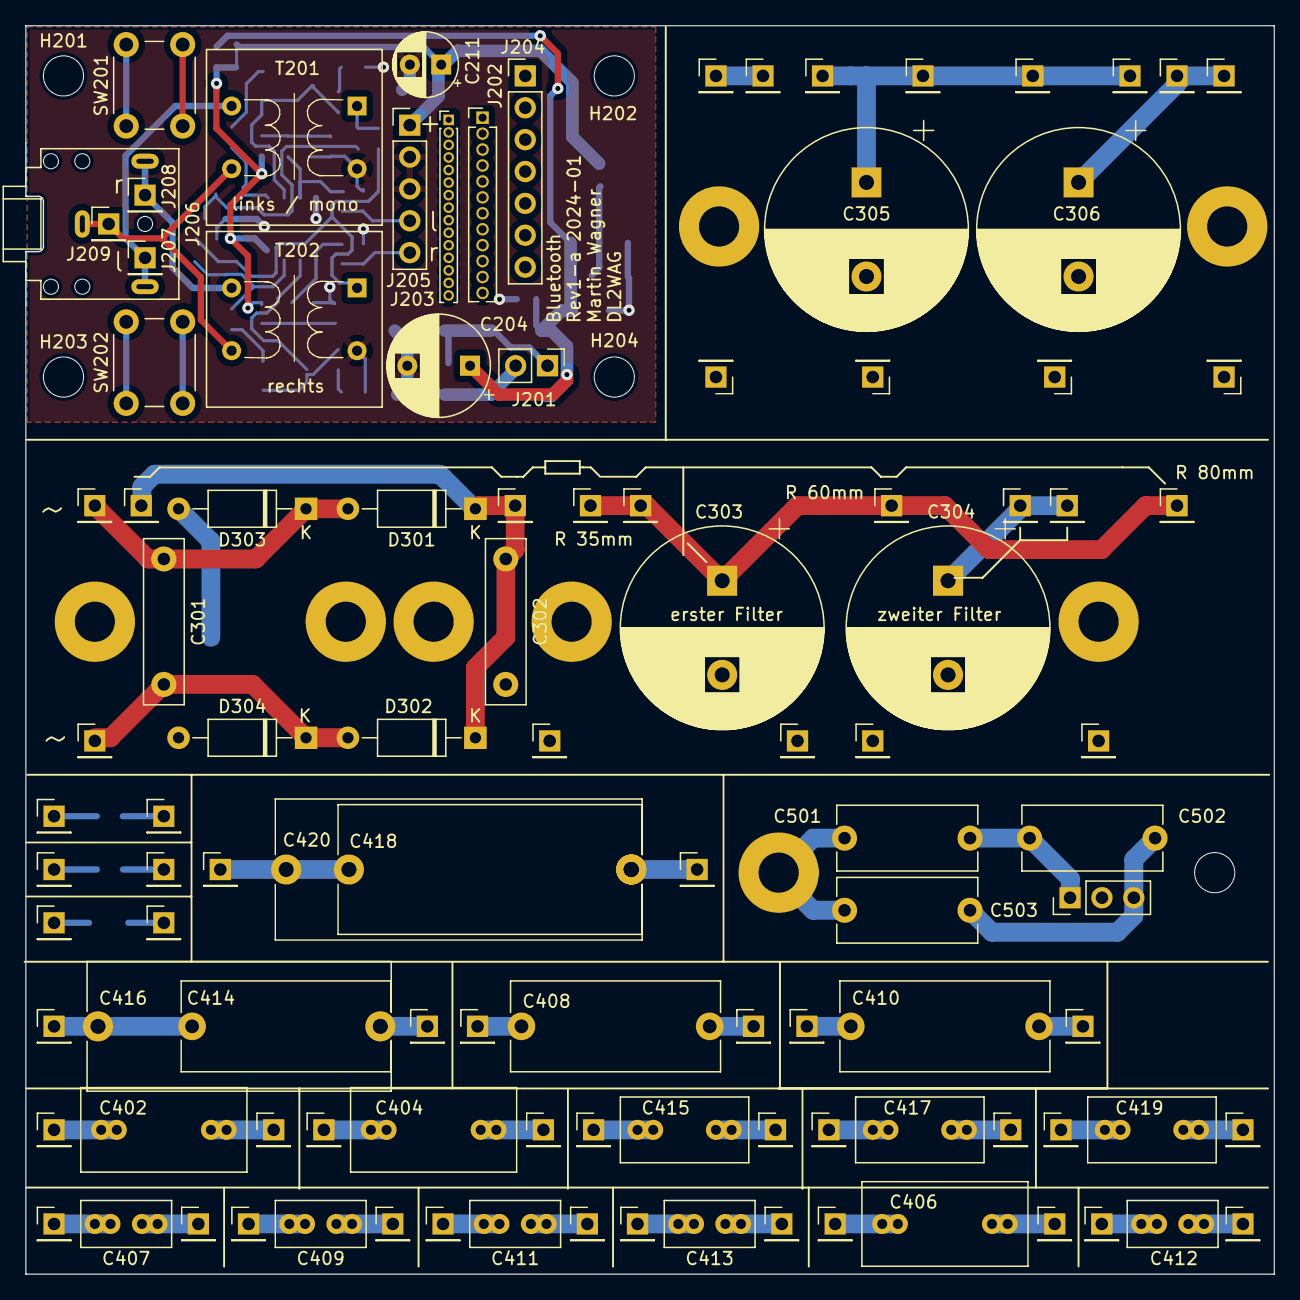
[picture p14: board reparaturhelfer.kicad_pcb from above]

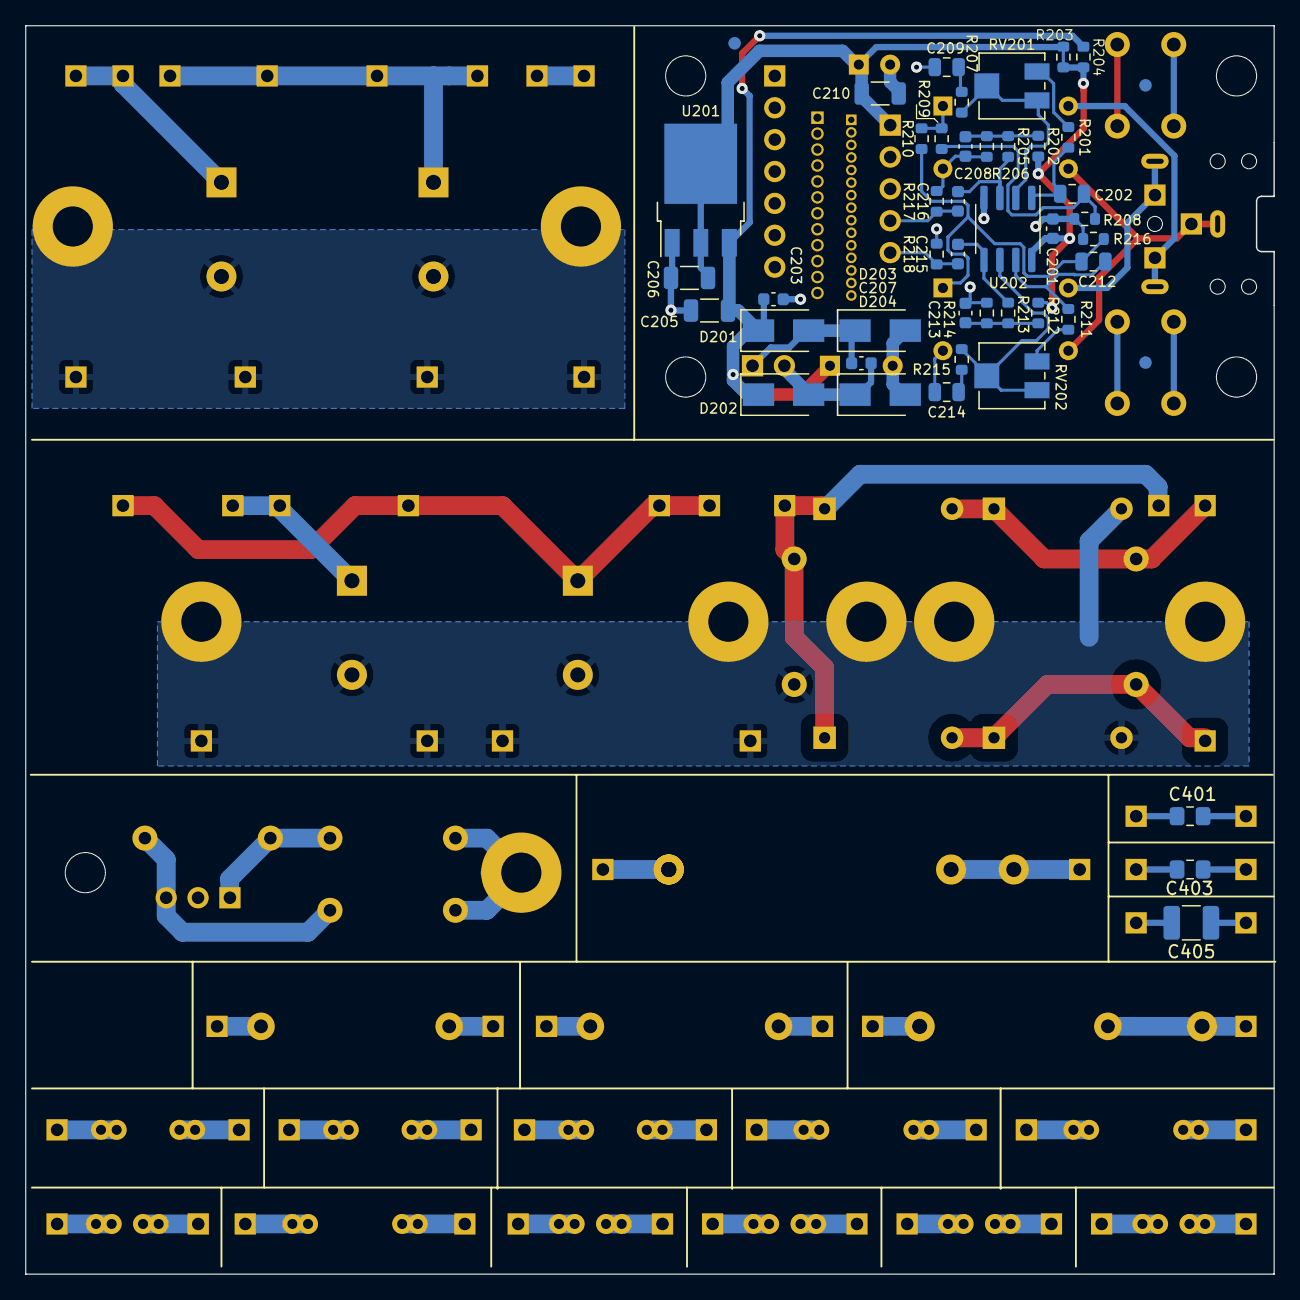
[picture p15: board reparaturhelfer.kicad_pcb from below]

Board: 2 copper layers, 99.5 x 99.5 mm, 167 parts (46 on the bottom side), 73 nets.

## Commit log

2024-01-04 Add: empty project
    [reparaturhelfer.kicad_pcb, reparaturhelfer.kicad_sch]
2024-01-04 Add: scm
    [adaptors.kicad_sch, bluetooth.kicad_sch, netzfilter.kicad_sch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]
2024-01-05 Add: Routing Bluetooth
    [adaptors.kicad_sch, bluetooth.kicad_sch, netzfilter.kicad_sch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]
2024-01-08 Add: PCB fertig
    [adaptors.kicad_sch, bluetooth.kicad_sch, netzfilter.kicad_sch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]
2024-01-08 add: Fertigungsdaten
    [reparaturhelfer-B_Cu.gbr, reparaturhelfer-B_Mask.gbr, reparaturhelfer-B_Paste.gbr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]
